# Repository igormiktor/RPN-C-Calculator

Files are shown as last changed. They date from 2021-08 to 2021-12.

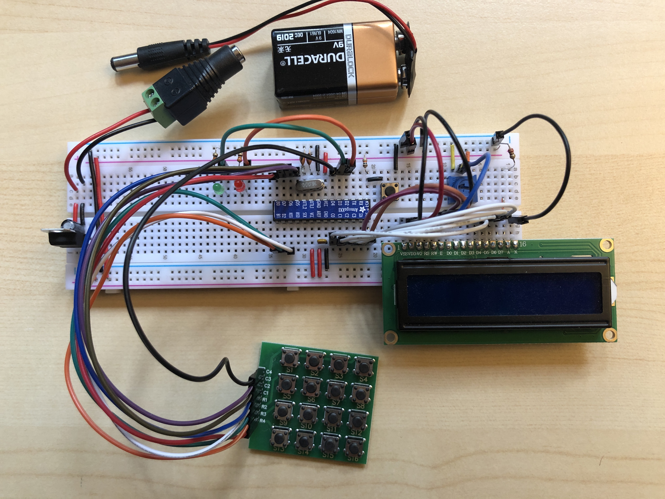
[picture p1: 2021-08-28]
Images/RPN_Calc_01.jpg

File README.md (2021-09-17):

# RPN-C-Calculator
An ATmega328-based RPN calculator in C++

This creates a simple four-function (+, - , *, /) RPN calculator
out of a bare ATmega328p chip wired to a 4x4 button keypad
(with classic row-column wiring) and a 2x16 LCD, all powered
by a 9V battery.

The calculator implements 32-bit floating point arithmetic using
a traditional four-level RPN stack (X, Y, Z, and T as in the
classic HP calculators).  The LCD displays the RPN X register
on the lower row and the RPN Y register on the upper row.

There are two LEDs.  They both flash at start-up just to confirm
operation.  While using the calculator, the green LED lights while
a number is being entered.  The red LED lights up when an overflow,
underflow, or NaN occurs (and an appropriate message displays on
the lower row of the LCD).

The keypad is set up as follows:

| | Col 1 | Col 2 | Col 3 | Col 4 |
| :---: | :---: | :---: | :---: | :---: |
| **Row 1** | 1 | 2 | 3 | / |
| **Row 2** | 4 | 5 | 6 | x |
| **Row 3** | 7 | 8 | 9 | - |
| **Row 4** | +/- | 0 | Enter | + |

Notice there is no decimal point key nor exponentiation ('E'
or 'EE') key.  Only integers can be entered directly: fractional
numbers or numbers in "scientific notation" must be entered by
either division or multiplication.  For example:

* To enter the number 123.456, the key strokes are:
    * 123456
    * 'Enter'
    * 1000
    * '/' (divide)
* To enter the number 1.0e16, the key strokes are:
    * 100000000
    * 'Enter'
    * 100000000
    * '*' (multiply)

This is a limitation of only having 16 keys, not of the chip
or software.  It would be possible to use chords to designate
the decimal point or 'E' keys, but that seemed rather
unintuitive and not worth the trouble.

The display automatically shifts to scientific notation whenever
needed.

A schematic of the circuit and a Fritzing wiring diagram (both in
PDF) are available in the Schematic folder, along with the Fritzing file.

Various design notes appear in the Notes folder.

The Images directory has photos of the calculator.

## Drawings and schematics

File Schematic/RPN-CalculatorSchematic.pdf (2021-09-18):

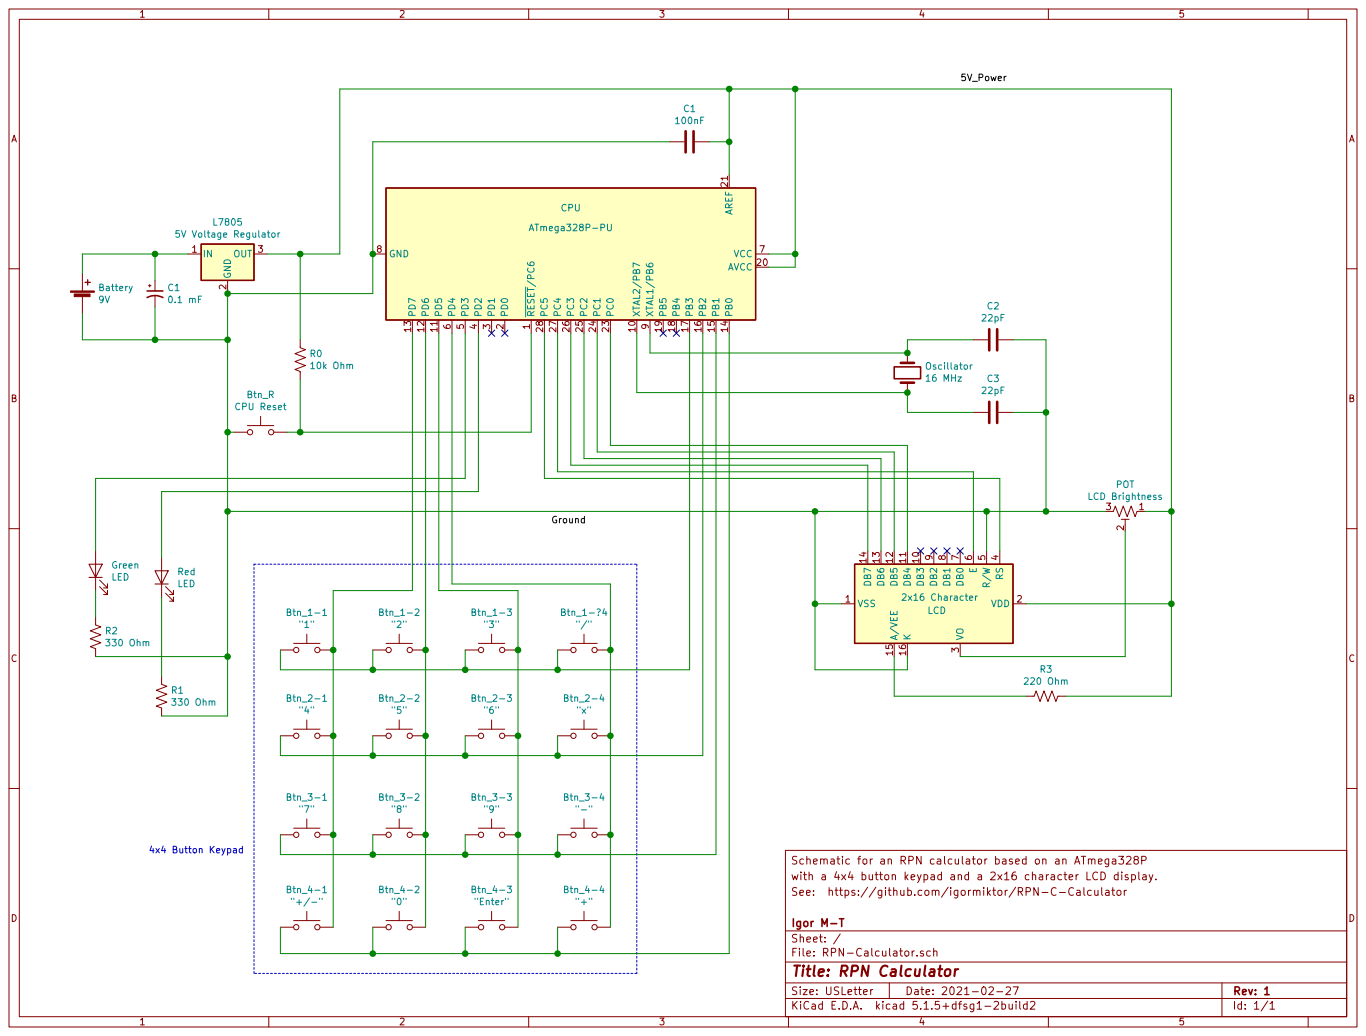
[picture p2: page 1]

Schematic for an RPN calculator based on an ATmega328P
with a 4x4 button keypad and a 2x16 character LCD display.

Btn_4-2 | "Enter" | "+"

See: https://github.com/igormiktor/RPN-C-Calculator

Igor M-T
Id: 1/1 Title: RPN Calculator File: RPN-Calculator.sch Sheet: /

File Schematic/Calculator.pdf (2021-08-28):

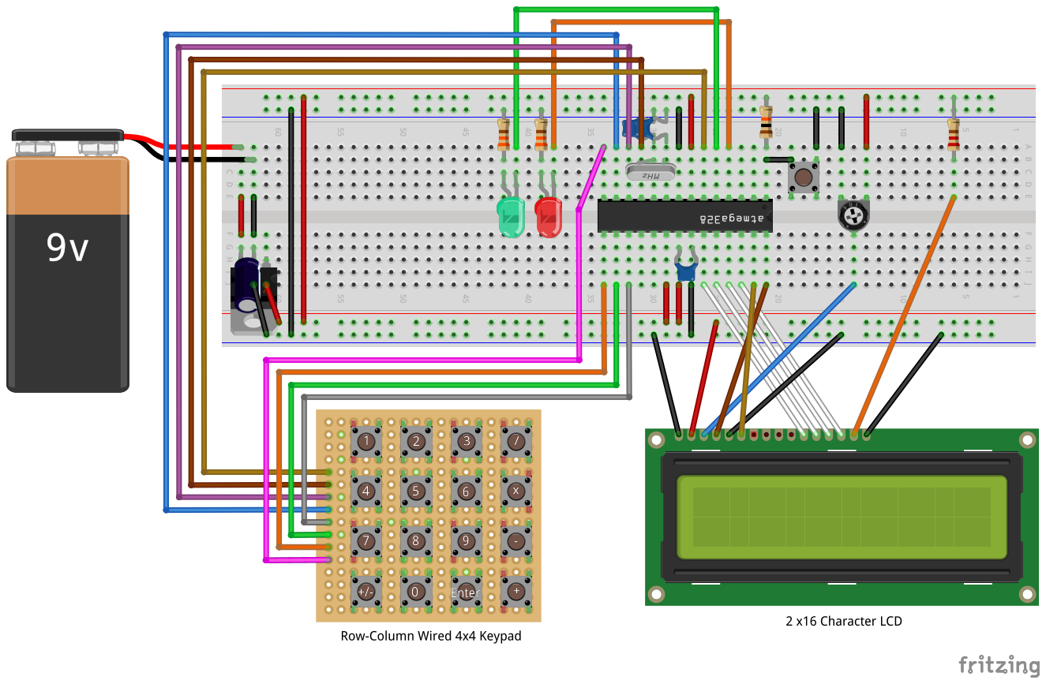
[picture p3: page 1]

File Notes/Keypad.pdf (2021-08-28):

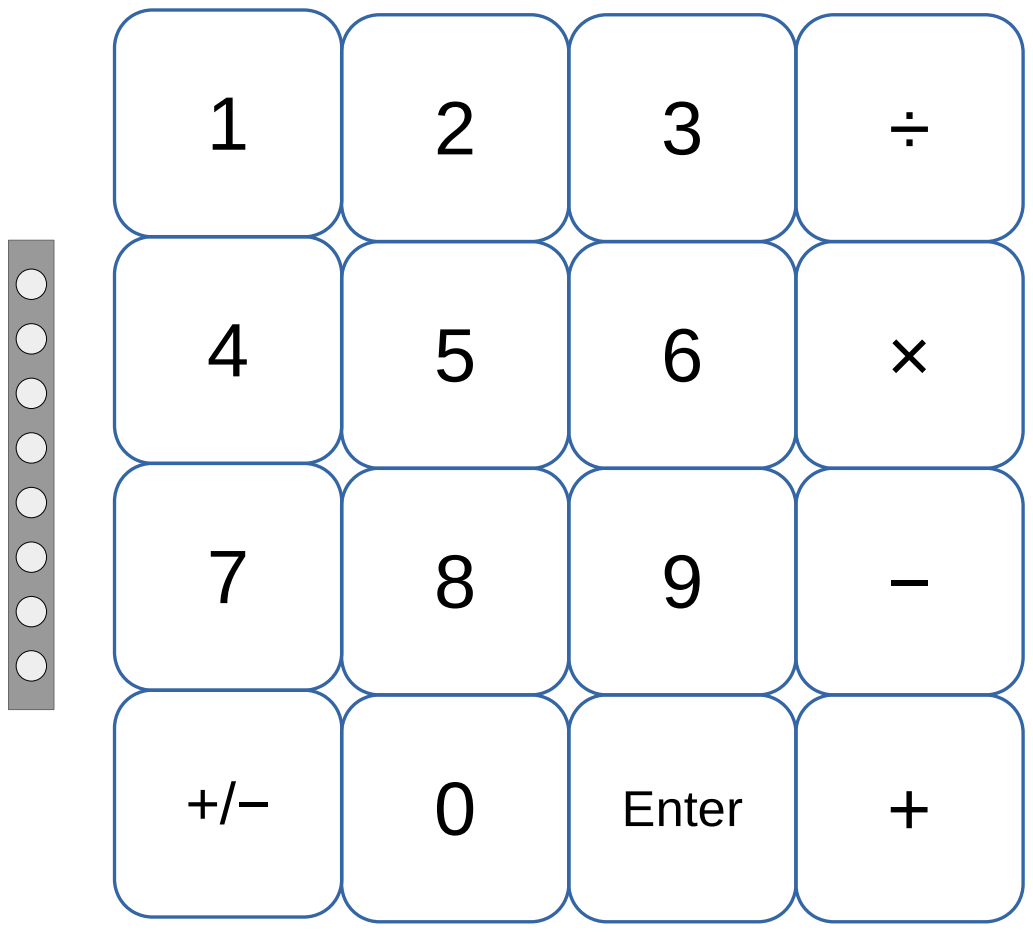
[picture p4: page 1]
Enter

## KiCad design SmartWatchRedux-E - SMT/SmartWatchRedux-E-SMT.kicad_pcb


Board: 2 copper layers, 24.7 x 69.9 mm, 6 parts (0 on the bottom side), 33 nets.

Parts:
BAT1: CR2032; BatteryHolder_Keystone_1060_1x2032
C1: 0.1uF; C_1206_3216Metric
CN1: 27C256Socket; DIP-28_W15.24mm
U1: ROM; DIP-28_W15.24mm_Socket
U2: DS1315; DIP-16_W7.62mm
Y1: 32.768 KHz; Crystal_SMD_3215-2Pin_3.2x1.5mm

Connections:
/XTAL1: U2.1, Y1.1
/XTAL2: U2.2, Y1.2
GND: BAT1.2, C1.2, CN1.14, U1.14, U2.5, U2.8, U2.14
unnamed: BAT1.1, U2.4
unnamed: CN1.1, U1.1, U2.13
unnamed: CN1.2, U1.2
unnamed: CN1.3, U1.3
unnamed: CN1.4, U1.4
unnamed: CN1.5, U1.5
unnamed: CN1.6, U1.6
unnamed: CN1.7, U1.7
unnamed: CN1.8, U1.8, U2.3
unnamed: CN1.9, U1.9
unnamed: CN1.10, U1.10, U2.6
unnamed: CN1.11, U1.11, U2.7
unnamed: CN1.12, U1.12
unnamed: CN1.13, U1.13
unnamed: CN1.15, U1.15
unnamed: CN1.16, U1.16
unnamed: CN1.17, U1.17
unnamed: CN1.18, U1.18
unnamed: CN1.19, U1.19
unnamed: CN1.20, U2.11
unnamed: CN1.21, U1.21
unnamed: CN1.22, U1.22, U2.12
unnamed: CN1.23, U1.23
unnamed: CN1.24, U1.24
unnamed: CN1.25, U1.25
unnamed: CN1.26, U1.26
unnamed: CN1.27, U1.27
unnamed: U1.20, U2.10
unnamed: U2.9, U2.15
VCC: C1.1, CN1.28, U1.28, U2.16

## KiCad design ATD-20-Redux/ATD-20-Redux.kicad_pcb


Board: 2 copper layers, 24.3 x 64.1 mm, 5 parts (0 on the bottom side), 9 nets.

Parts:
BAT1: CR2032; BatteryHolder_Keystone_1060_1x2032
C1: 0.1uF; C_Disc_D4.3mm_W1.9mm_P5.00mm
J1: RTC Pins; DIP-28_W15.24mm_Socket
U1: DS1315; DIP-16_W7.62mm
Y1: 32.768 KHz; Crystal_C38-LF_D3.0mm_L8.0mm_Horizontal

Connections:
/D0: J1.11, U1.6, U1.7
/XTAL1: U1.1, Y1.1
/XTAL2: U1.2, Y1.2
/~CS_RTC: J1.20, U1.11
/~IOR: J1.22, U1.12
/~IOW: J1.27, U1.3
GND: BAT1.2, C1.2, J1.14, U1.5, U1.8, U1.9, U1.14
unnamed: BAT1.1, U1.4
VCC: C1.1, J1.28, U1.13, U1.16

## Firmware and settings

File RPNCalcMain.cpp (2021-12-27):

/*
    RPNCalcMain.cpp - main program and immediately supporting code

    Copyright (c) 2021 Igor Mikolic-Torreira

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
    THE SOFTWARE IS PROVIDED "AS IS", WITHOUT WARRANTY OF ANY KIND, EXPRESS OR
    IMPLIED, INCLUDING BUT NOT LIMITED TO THE WARRANTIES OF MERCHANTABILITY,
    FITNESS FOR A PARTICULAR PURPOSE AND NONINFRINGEMENT. IN NO EVENT SHALL THE
    AUTHORS OR COPYRIGHT HOLDERS BE LIABLE FOR ANY CLAIM, DAMAGES OR OTHER
    LIABILITY, WHETHER IN AN ACTION OF CONTRACT, TORT OR OTHERWISE, ARISING FROM,
    OUT OF OR IN CONNECTION WITH THE SOFTWARE OR THE USE OR OTHER DEALINGS IN THE
    SOFTWARE.
*/


#include <inttypes.h>

#include <avr/interrupt.h>
#include <util/atomic.h>

#include "AVRTools/GpioPinMacros.h"
#include "AVRTools/InitSystem.h"
#include "AVRTools/SystemClock.h"

#include "PinAssignments.h"
#include "KeyPad.h"
#include "Lcd.h"
#include "RpnStack.h"
#include "DisplayFloat.h"

// #define pRedLed     GpioPin( B, 0 )


void displayStack( RpnStack& stack, Lcd& lcd );
void initializeWatchTimer();
void clearWatchTimerFlag();
void updateWatchIcon( Lcd& theLcd );
void startNumericEntryMode();
void endNumericEntryMode();
void doNumericKey( RpnStack& stack, uint8_t value );
void doEnterKey( RpnStack& stack );
void displayStack( RpnStack& stack, Lcd& lcd );



// Helper class to manage flags
class FlagType
{
public:
    FlagType() : mMode( false ) {}

    bool isSet() { return mMode; }

    void clear() { mMode = false; }
    void set() { mMode = true; }

private:
    bool mMode;
};


// Flag to indicate when we are in numeric entry mode
FlagType gNumericEntryMode;

// Flag to indicate that prior key was "Enter"
FlagType gPreviousKeyWasEnter;

// Flag to indicate the 1-second clock tick
volatile FlagType gTimer1SecondFlag;





int main()
{
    initSystem();
    initSystemClock();

    setGpioPinModeOutput( pRedLed );
    setGpioPinModeOutput( pGreenLed );
    setGpioPinHigh( pRedLed );
    setGpioPinHigh( pGreenLed );

    Lcd theLcd;
    theLcd.init();
    //                     0123456789012345
    theLcd.displayTopRow( "RPN Calculator+" );

    configureKeyPad();

    initializeWatchTimer();

    RpnStack stack;

    delayMilliseconds( 2000 );

    // We are ready to start
    setGpioPinLow( pRedLed );
    setGpioPinLow( pGreenLed );
    //                     0123456789012345
    theLcd.displayTopRow( "Press any key..." );

    // These are to manage button press delays to debounce buttons
    const unsigned int kMinTimeBetweenButtonChecks = 250;       // milliseconds
    unsigned long nextTimeButtonPressAccepted = 0;

    // Use this to know to clear LCD on the first keystroke
    bool isFirstKeyStroke = true;

    while ( 1 )
    {
        if ( gTimer1SecondFlag.isSet() )
        {
            clearWatchTimerFlag();
            updateWatchIcon( theLcd );
        }

        if ( keyPressed() && millis() > nextTimeButtonPressAccepted )
        {
            // Clear top row on first keystroke
            if ( isFirstKeyStroke )
            {
                isFirstKeyStroke = false;
                theLcd.clearTopRow();
            }

            uint8_t keyNbr = getKeyPressed();
            theLcd.clearBottomRow();
            theLcd.setCursor( 1, 15 );
            switch ( keyNbr )
            {
                // Numeric keys...

                case kKeyZero:
                    doNumericKey( stack, 0 );
                    break;

                case kKeyOne:
                    doNumericKey( stack, 1 );
                    break;

                case kKeyTwo:
                    doNumericKey( stack, 2 );
                    break;

                case kKeyThree:
                    doNumericKey( stack, 3 );
                    break;

                case kKeyFour:
                    doNumericKey( stack, 4 );
                    break;

                case kKeyFive:
                    doNumericKey( stack, 5 );
                    break;

                case kKeySix:
                    doNumericKey( stack, 6 );
                    break;

                case kKeySeven:
                    doNumericKey( stack, 7 );
                    break;

                case kKeyEight:
                    doNumericKey( stack, 8 );
                    break;

                case kKeyNine:
                    doNumericKey( stack, 9 );
                    break;


                // Non-numeric keys...

                case kKeyEnter:
                    endNumericEntryMode();
                    doEnterKey( stack );
                    break;

                case kKeyChangeSign:
                    stack.changeSign();
                    gPreviousKeyWasEnter.clear();
                    break;

                case kKeyAdd:
                    endNumericEntryMode();
                    stack.add();
                    gPreviousKeyWasEnter.clear();
                    break;

                case kKeySubtract:
                    endNumericEntryMode();
                    stack.subtract();
                    gPreviousKeyWasEnter.clear();
                    break;

                case kKeyMultiply:
                    endNumericEntryMode();
                    stack.multiply();
                    gPreviousKeyWasEnter.clear();
                    break;

                case kKeyDivide:
                    endNumericEntryMode();
                    stack.divide();
                    gPreviousKeyWasEnter.clear();
                    break;

                default:
                    break;
            }

            displayStack( stack, theLcd );

            nextTimeButtonPressAccepted = millis() + kMinTimeBetweenButtonChecks;
        }

    }

}



void doNumericKey( RpnStack& stack, uint8_t value )
{
    if ( !gNumericEntryMode.isSet() )
    {
        // Enter numeric entry mode
        startNumericEntryMode();

        // Only lift the stack if previous key was NOT enter and
        // don't currently have a NaN or Inf in X.
        // NOTE: in a real calculator, want the NaN/Inf to propagate,
        // but in this calculator there is no way to clear these.  So
        // this is a bit of a hack.
        if ( !gPreviousKeyWasEnter.isSet() && !stack.isNanX()
                && !stack.isInfiniteX() )
        {
            stack.lift();
        }

        // Always clear X
        stack.clearX();
    }

    // Once in numeric entry mode, we add the number we are accumulating to the stack X
    stack.addDigitToX( value );
    gPreviousKeyWasEnter.clear();
    if ( stack.isInfiniteX() )
    {
        // Set the warning LED to indicate the INF
        setGpioPinHigh( pRedLed );

        // Causing an overflow on digit entry clears numeric entry mode
        // This allow user to re-start entering a number (which clears X)
        // No other choice since we don't have a clear or backspace key...
        // Numeric entry LED stays on to indicate this
        gNumericEntryMode.clear();
        // Pretend previous key as a stack lift to avoid re-lifting the stack
        gPreviousKeyWasEnter.set();

        // Note that we don't just clear X at this time because we need
        // to display the infinte X together with the INF (red) Led.
    }
}



void doEnterKey( RpnStack& stack )
{
    stack.lift();
    gPreviousKeyWasEnter.set();
}



void startNumericEntryMode()
{
    setGpioPinHigh( pGreenLed );
    gNumericEntryMode.set();
}


void endNumericEntryMode()
{
    setGpioPinLow( pGreenLed );
    gNumericEntryMode.clear();
}



void displayStack( RpnStack& stack, Lcd& lcd )
{
    // Set NAN and OVF LCD accordingly
    displayFloat( stack.Y(), 0, lcd );
    uint8_t ret = displayFloat( stack.X(), 1, lcd );

    // Set NaN/Inf indicator LED accordingly
    switch ( ret )
    {
        case kNan:
        case kInfinity:
            setGpioPinHigh( pRedLed );
            break;

        default:
            setGpioPinLow( pRedLed );
            break;
    }
}



ISR( TIMER1_COMPA_vect )
{
    gTimer1SecondFlag.set();
}



void initializeWatchTimer()
{
    // Select CTC mode with prescalar = 256
    TCCR1B = ( 1 << WGM12 ) | ( 1 << CS12 );

    // "Top" value for 1Hz output with prescalar of 256
    const uint16_t kTimer1At1Hz  = 62449;
    // Load the CompA "top" counter value
    OCR1A = kTimer1At1Hz;

    // Enable the CompA interrupt for Timer1
    TIMSK1 = ( 1 << OCIE1A );
}



void clearWatchTimerFlag()
{
    ATOMIC_BLOCK( ATOMIC_RESTORESTATE )
    {
        gTimer1SecondFlag.clear();
    }
}



void updateWatchIcon( Lcd& theLcd )
{
    static uint8_t iconCounter = 0;

    ++iconCounter;
    iconCounter %= 4;

    theLcd.setCursor( 1, 0 );
    theLcd.write( static_cast<char>( iconCounter ) );
}

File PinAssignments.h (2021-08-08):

/*
    PinAssignments.h - GPIO pin assignments

    Copyright (c) 2021 Igor Mikolic-Torreira

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
    THE SOFTWARE IS PROVIDED "AS IS", WITHOUT WARRANTY OF ANY KIND, EXPRESS OR
    IMPLIED, INCLUDING BUT NOT LIMITED TO THE WARRANTIES OF MERCHANTABILITY,
    FITNESS FOR A PARTICULAR PURPOSE AND NONINFRINGEMENT. IN NO EVENT SHALL THE
    AUTHORS OR COPYRIGHT HOLDERS BE LIABLE FOR ANY CLAIM, DAMAGES OR OTHER
    LIABILITY, WHETHER IN AN ACTION OF CONTRACT, TORT OR OTHERWISE, ARISING FROM,
    OUT OF OR IN CONNECTION WITH THE SOFTWARE OR THE USE OR OTHER DEALINGS IN THE
    SOFTWARE.
*/

#ifndef PinAssignments_h
#define PinAssignments_h

#include "AVRTools/GpioPinMacros.h"


/*******************************************************************
********************************************************************

 P I N   A S S I G N M E N T S

********************************************************************
*******************************************************************/
/*
    ATmega328p Package = 28-pin-PDIP
    1: Reset                                      --> Reset switch
    2: PD0 RXD0 PCINT16
    3: PD1 TXD0 PCINT17
    4: PD2 INT0 PCINT18                           --> Red LED
    5: PD3 INT1 OC2B PCINT19                      --> Green LED
    6: PD4 T0 XCK0 PCINT20                        --> Keypad Column 4
    7: Vcc                                        --> +5V
    8: Gnd                                        --> Ground
    9: PB6 TOSC1 XTAL1 PCINT6                     --> 16 MHz Oscillator
    10: PB7 TOSC2 XTAL2 PCINT7                    --> 16 MHz Oscillator
    11: PD5 T1 OC0B PCINT21                       --> Keypad Column 3
    12: PD6 AIN0 OC0A PCINT22                     --> Keypad Column 2
    13: PD7 AIN1 PCINT23                          --> Keypad Column 1
    14: PB0 ICP1 CLKO PCINT0                      --> Keypad Row 4
    15: PB1 OC1A PCINT1                           --> Keypad Row 3
    16: PB2 SS OC1B PCINT2                        --> Keypad Row 2
    17: PB3 MOSI OC2A PCINT3                      --> Keypad Row 1
    18: PB4 MISO PCINT4
    19: PB5 USCK PCINT5
    20: AVCC                                      --> +5V
    21: AREF                                      --> +5V
    22: Gnd                                       --> Ground
    23: PC0 ADC0 PCINT8                           --> LCD Pin D4 (Data)
    24: PC1 ADC1 PCINT9                           --> LCD Pin D5 (Data)
    25: PC2 ADC2 PCINT10                          --> LCD Pin D6 (Data)
    26: PC3 ADC3 PCINT11                          --> LCD Pin D7 (Data)
    27: PC4 ADC4 SDA PCINT12                      --> LCD Pin E  (Enable)
    28: PC5 ADC5 SCL PCINT13                      --> LCD Pin RS (Data/Cmd Select)
*/


// Implement GPIO pin assignments

#define pRedLed         GpioPin( D, 2 )
#define pGreenLed       GpioPin( D, 3 )

#define pKeyPadCol4     GpioPin( D, 4 )
#define pKeyPadCol3     GpioPin( D, 5 )
#define pKeyPadCol2     GpioPin( D, 6 )
#define pKeyPadCol1     GpioPin( D, 7 )
#define pKeyPadRow4     GpioPin( B, 0 )
#define pKeyPadRow3     GpioPin( B, 1 )
#define pKeyPadRow2     GpioPin( B, 2 )
#define pKeyPadRow1     GpioPin( B, 3 )

#define pLcdD7          GpioPin( C, 3 )
#define pLcdD6          GpioPin( C, 2 )
#define pLcdD5          GpioPin( C, 1 )
#define pLcdD4          GpioPin( C, 0 )
#define pLcdEnable      GpioPin( C, 4 )
#define pLcdDataSelect  GpioPin( C, 5 )


#endif  // PinAssignments_h

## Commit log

2021-08-14 Fix special case handling
2021-08-28 Correct how we start numeric entry mode
    [RPNCalcMain.cpp]
2021-08-28 Add schematic
    [Calculator.fzz]
2021-09-12 Add actual schematic
2021-09-12 Improved annotation and layout of wires
2021-09-12 Ignore KiCad backup files
2021-09-12 Add KiCad schematic files
    [RPN-Calculator.kicad_pcb, RPN-Calculator.sch]
2021-09-12 Label Gnd and 5V wires
    [Calculator2.fzz, Calculator3.fzz, RPN-Calculator.sch]
2021-09-12 Discard erroneously committed files
    [Calculator2.fzz, Calculator3.fzz]
2021-09-12 Add KiCad cache file ending in *.lib
2021-09-12 Correct handling of KiCad ignored files
2021-09-12 Remove KiCad file that should not be tracked
2021-09-12 Update gitignores for KiCad
2021-09-12 Reposition LCD wires in schematic
    [RPN-Calculator.sch]
2021-09-18 Correct schematic button label '9'
    [RPN-Calculator.sch]
2021-12-27 Add missing volatile for proper optimizer codegen
    [RPNCalcMain.cpp]
